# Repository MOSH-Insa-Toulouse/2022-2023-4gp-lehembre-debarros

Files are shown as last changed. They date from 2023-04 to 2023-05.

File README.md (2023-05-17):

# 2022-2023-4gp-lehembre-debarros

## SOMMAIRE 

1. Etapes de fabrication
2. Présentation du capteur graphite 
3. Simulations sous LtSpice
4. Circuit électronique
5. Eléments nécessaires au projet
6. Elaboration du shield sous KiCAD
7. Programme Arduino
8. Application Android
9. Banc de test
10. Datasheet 

# 1. Etapes de fabrication

- Création du circuit et simulations sous LtSpice
- Implémentation du circuit sous KiCAD et élaboration du PCB 
- Fabrication du PCB
- Percage de la plaquette et soudure des composants 
- Elaboration du code Arduino
- Création de l'application d'interfacage sous MIT - app inventor
- Caractérisation du capteur

# 2. Présentation du capteur graphite 

Le capteur est basé sur l'effet tunnel quantique entre les particules de graphite déposées par le crayon. 
Pour plus d'informations, vous pouvez vous renseigner grâce au lien suivant : [Informations supplémentaires](https://github.com/MOSH-Insa-Toulouse/2022-2023-4gp-lehembre-debarros/blob/d776b440ef20fb4f5e64abb67d3f56df1f3a449e/++Publi%20Pencil%20Drawn%20Strain%20Gauges-srep03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)

Dimensions : 



Utilisation d'un crayon HB pour le grain.

# 3. Simulations sous LtSpice

Etude et dimensionnement du gain et des capacités afin d’obtenir un signal exploitable en simulant le circuit : 



La résistance du capteur est calculé grâce à la formule suivante : 𝑅_𝐶=((𝑅_3+𝑅_2) 𝑅_1 𝑉_𝐶𝐶)/(𝑅_2 𝑉_𝐴𝐷𝐶)−𝑅_5−𝑅_1

# 4. Circuit électronique 

Schéma de l'amplificateur de signal :
 


Modules supplémentaires et leur connexions : 



Connection des pins entre le PCB et la carte Arduino



# 5. Eléments nécessaires au projet 

-	Arduino Uno
-	Module Bluetooth HC05
-	Amplificateur LTC1050 
-	I2C Ecran OLED Joy-it SBC-OLED01
-	Encodeur rotatoire avec boutton poussoir (Joy-it KY-040) 
-	Spectrasymbol 005 21 Flex Sensor
-	MCP41050 SPI Potentiomètre Digital 

# 6. Elaboration du PCB sous KiCAD

Représentation du PCB avec le circuit implémenté : 



Empruntes des autres composants : 



# 7. Programme Arduino

Ci-après, le code Arduino utilisé : [Code Arduino](https://github.com/MOSH-Insa-Toulouse/2022-2023-4gp-lehembre-debarros/blob/07b504035136efd2108f1f7b01446d1b1bee7c57/Code_arduino_Lauriane_Alan.ino)

# 8. Application Android

L'APK est disponible à cette adresse : [APK](https://github.com/MOSH-Insa-Toulouse/2022-2023-4gp-lehembre-debarros/blob/c0ea48ad6c8dff68e6e4c520c7baa0256ce2a0f2/Capteur_Graphite_Final.apk)



# 9. Banc de test

Pour calibrer notre capteur, nous avons utilisé le banc de test mis à notre disposition. 



Nous avons ainsi obtenu les variations relatives suivantes en tension et en compression : 
 

Notre capteur dispose ainsi d'une sensibilité de 0,675 GΩ/% en compression et 0,2GΩ/% en tension.

Cette sensibilité correspond au coefficient de la pente de la variation relative par rapport à la déformation. 
La déformation se calcule à l'aide de la formule suivante : ɛ = e/(2.R).

- ɛ : déformation
- e : épaisseur du papier utilisé (0,16mm ici)
- R : rayon de la courbe

These values are for comparative use only to get orders of magnitude, they are very unstable until the sensor is stabilized in a specialized housing. 

# 10. Datasheet

La datasheet est disponible en suivante le lien ci-après : [Datasheet](https://github.com/MOSH-Insa-Toulouse/2022-2023-4gp-lehembre-debarros/blob/0e1e4ce1e155748c3f02e4ec9dddf21011c97965/Datasheet%20-%20Capteur-final.pdf)

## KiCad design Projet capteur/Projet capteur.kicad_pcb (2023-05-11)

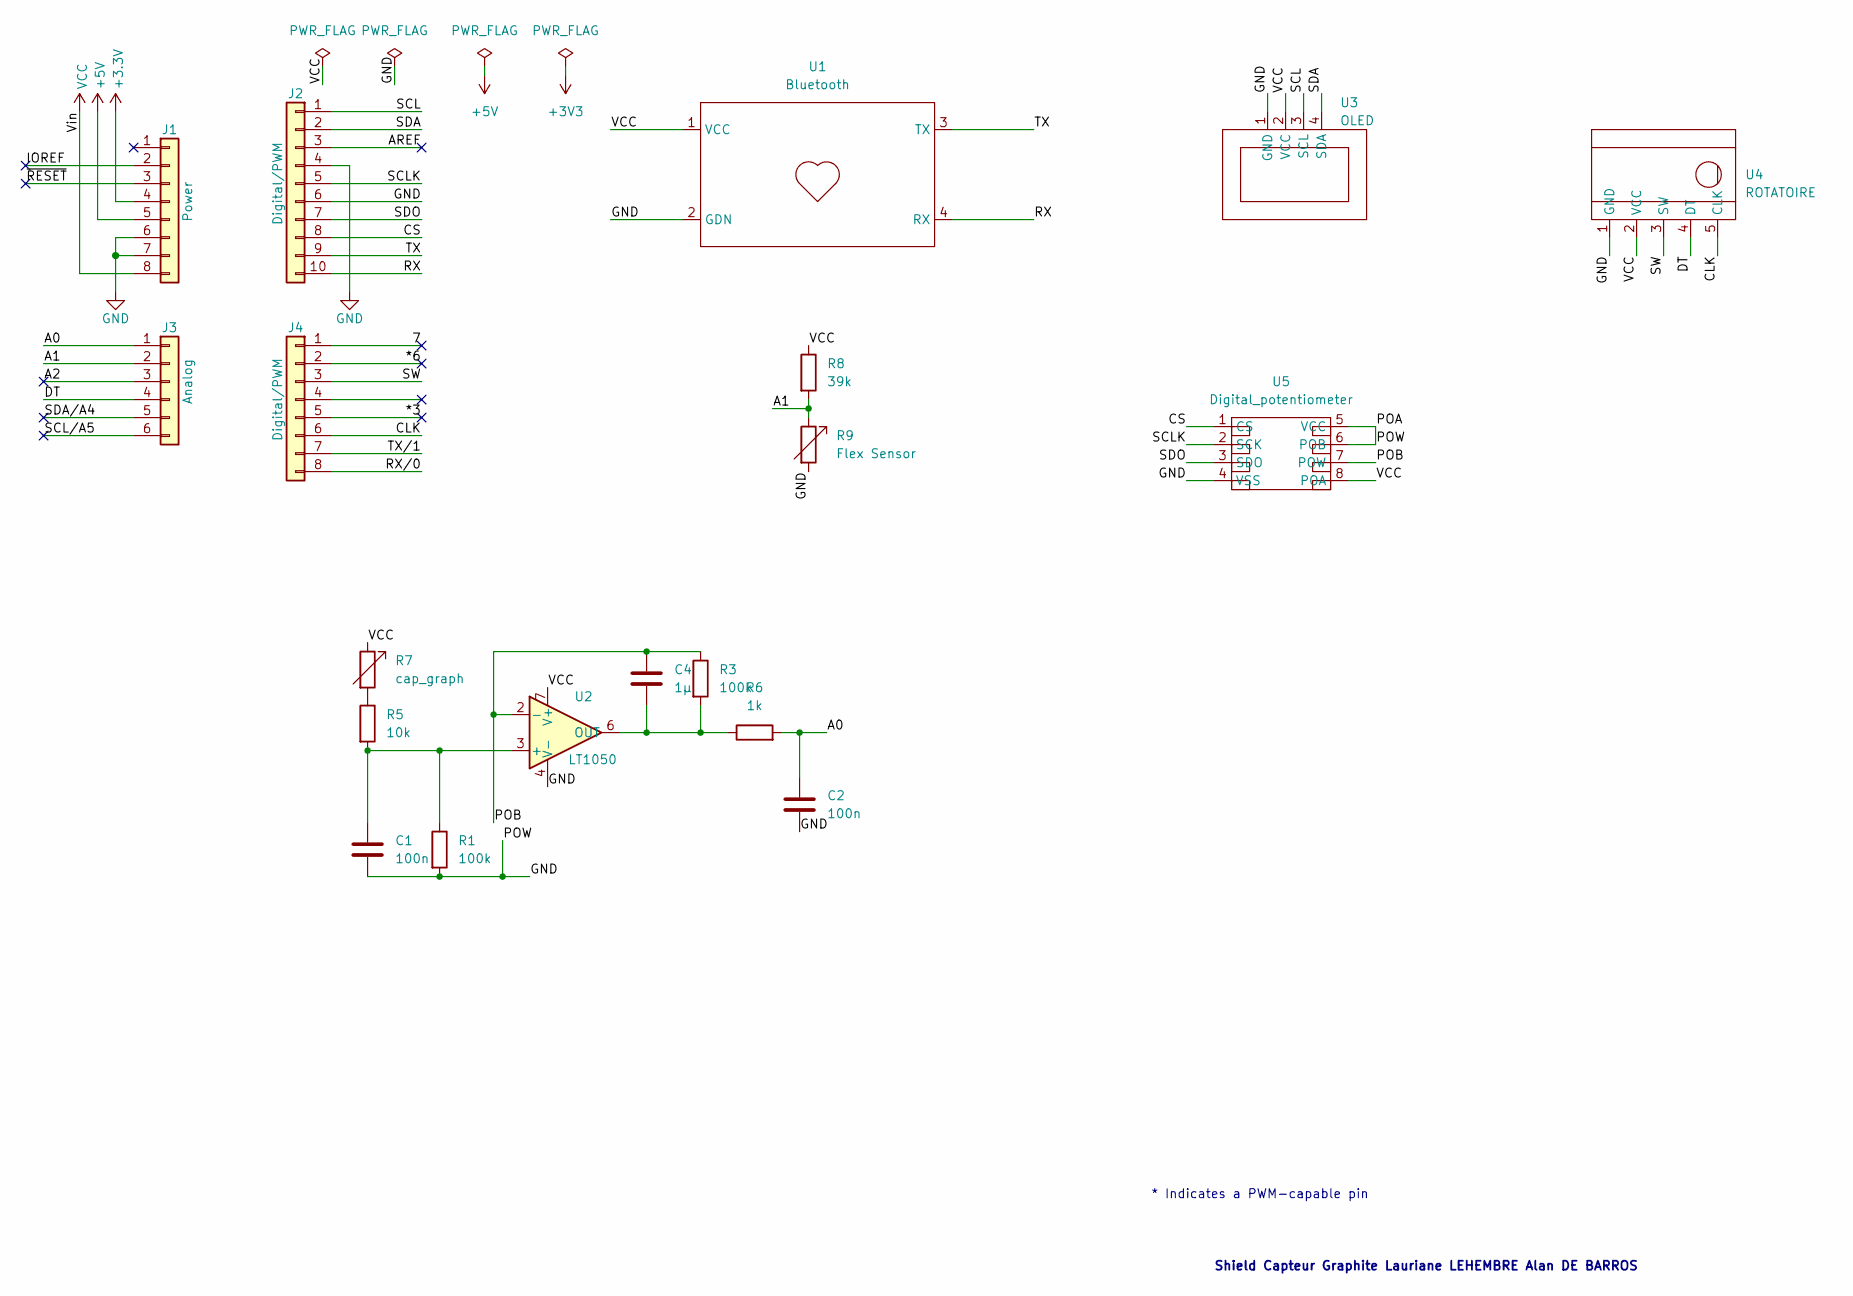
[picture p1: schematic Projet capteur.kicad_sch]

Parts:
C1, C2: 100n; capa
C4: 1µ; C4
J1: Power; PinSocket_1x08_P2.54mm_Vertical
J2: Digital/PWM; PinSocket_1x10_P2.54mm_Vertical
J3: Analog; PinSocket_1x06_P2.54mm_Vertical
J4: Digital/PWM; PinSocket_1x08_P2.54mm_Vertical
R1, R3: 100k; Resistance
R5: 10k; Resistance
R6: 1k; Resistance
R7: cap_graph; Flex_sensor
R8: 39k; Resistance
R9: Flex Sensor; Flex_sensor
U1: Bluetooth; Bluetooth_4pattes
U2: LT1050; DIP-8_W7.62mm_LongPads
U3: OLED
U4: ROTATOIRE; Rotatoire
U5: Digital_potentiometer; Pot_Digital

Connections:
+3V3: J1.4
+5V: J1.5
/7: J4.1
/*3: J4.5
/*6: J4.2
/A0: C2.1, J3.1, R6.2
/A1: J3.2, R8.2, R9.1
/A2: J3.3
/AREF: J2.3
/CLK: J4.6, U4.5 (CLK)
/CS: J2.8, U5.1 (CS)
/DT: J3.4, U4.4 (DT)
/IOREF: J1.2
/POB: C4.1, R3.1, U2.2 (-), U5.7 (POW)
/RX: J2.10, U1.4 (RX)
/RX/0: J4.8
/SCL: J2.1, U3.3 (SCL)
/SCLK: J2.5, U5.2 (SCK)
/SCL/A5: J3.6
/SDA: J2.2, U3.4 (SDA)
/SDA/A4: J3.5
/SDO: J2.7, U5.3 (SDO)
/SW: J4.3, U4.3 (SW)
/TX: J2.9, U1.3 (TX)
/TX/1: J4.7
/~RESET: J1.3
GND: C1.2, C2.2, J1.6, J1.7, J2.4, J2.6, R1.2, R9.2, U1.2 (GDN), U2.4 (V-), U3.1 (GND), U4.1 (GND), U5.4 (VSS), U5.5 (VCC), U5.6 (POB)
unnamed: R5.1, R7.2
unnamed: C1.1, R1.1, R5.2, U2.3 (+)
unnamed: C4.2, R3.2, R6.1, U2.6 (OUT)
VCC: J1.8, R7.1, R8.1, U1.1 (VCC), U2.7 (V+), U3.2 (VCC), U4.2 (VCC), U5.8 (POA)

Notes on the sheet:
Shield Capteur Graphite Lauriane LEHEMBRE Alan DE BARROS
* Indicates a PWM-capable pin

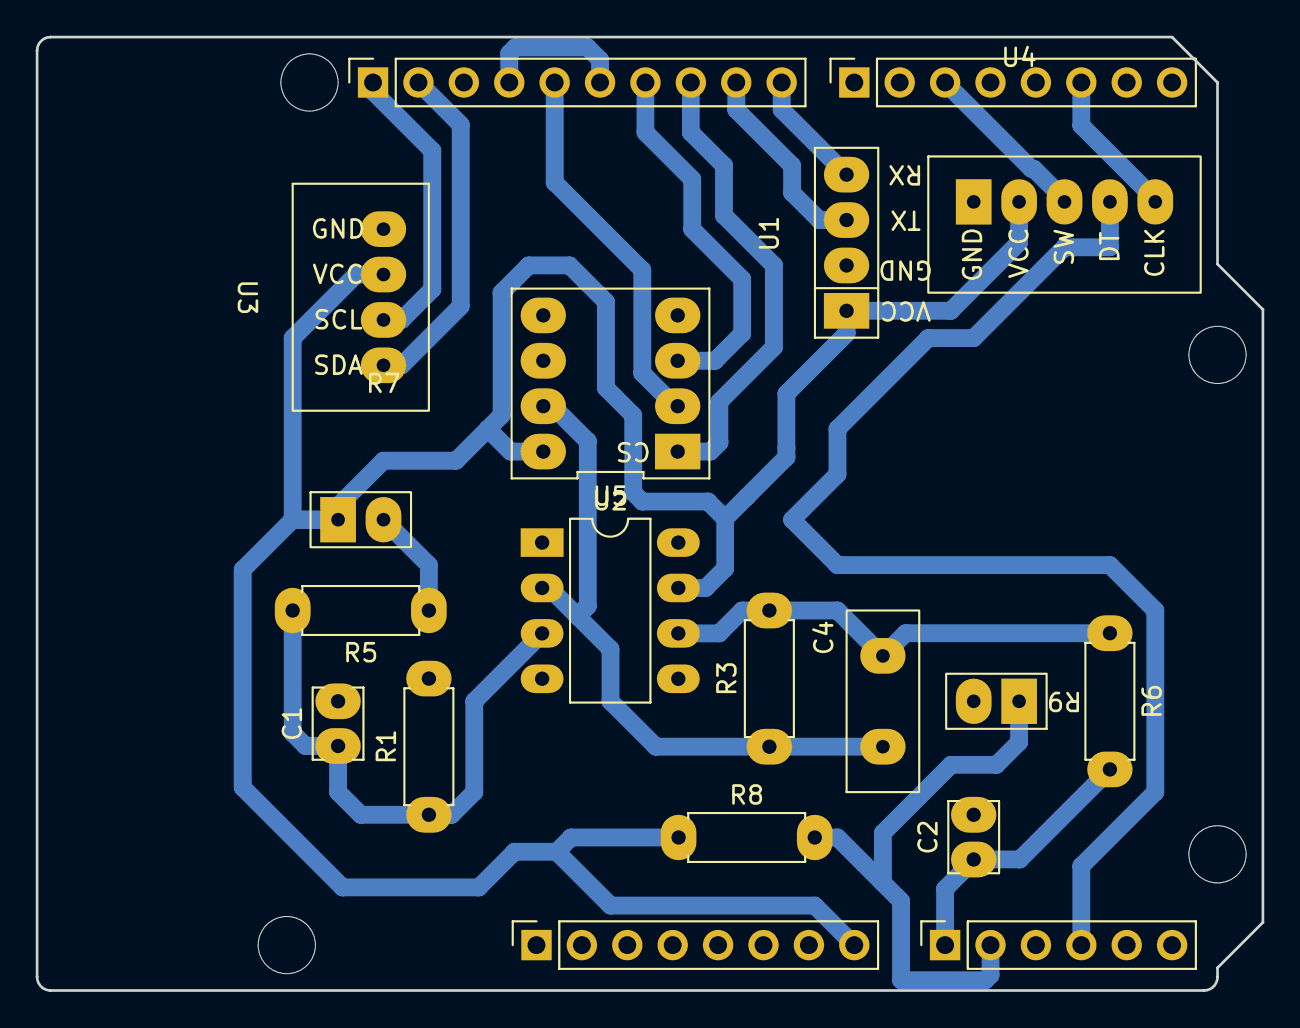
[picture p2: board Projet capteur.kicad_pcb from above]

Board: 2 copper layers, 68.6 x 53.3 mm, 23 parts (0 on the bottom side), 18 nets.

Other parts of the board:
MH1, MH2, MH3, MH4: MountingHole_3.2mm

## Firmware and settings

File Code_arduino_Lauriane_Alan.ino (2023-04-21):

#include <SoftwareSerial.h>
#include <SPI.h>
#include <Adafruit_SSD1306.h>

////////////////////////////////////////////////////////////////////////////////////////////////////////
#define nombreDePixelsEnLargeur 128         // Taille de l'écran OLED, en pixel, au niveau de sa largeur
#define nombreDePixelsEnHauteur 64          // Taille de l'écran OLED, en pixel, au niveau de sa hauteur
#define brocheResetOLED         -1          // Reset de l'OLED partagé avec l'Arduino (d'où la valeur à -1, et non un numéro de pin)
#define adresseI2CecranOLED     0x3C  
#define encoder0PinA  2  //CLK Output A Do not use other pin for clock as we are using interrupt
#define encoder0PinB  4  //DT Output B
#define Switch 5 // Switch connection if available
#define MCP_NOP 0b00000000
#define MCP_WRITE 0b00010001
#define MCP_SHTDWN 0b00100001
#define txPin 8   //Broche 11 en tant que RX, TX du HC-05
#define rxPin 9   //Broche 10 en tant que TX, RX du HC-05
#define baudrate 9600
////////////////////////////////////////////////////////////////////////////////////////////////////////

const int ssMCPin = 10; // Define the slave select for the digital pot
volatile unsigned int encoder0Pos = 0; //Valeur de position de l'encodeur rotatoire
int in_menu = 0; //Booleen permettant de switch entre menu et fonctionnalités
int last_pos_encodeur = 0; //Dernière position de l'encodeur rotatoire, pour savoir si la position a changé depuis le dernier tour de boucle
int pos_menu = 1; //Position dans le menu 
float R2 = 5*196.08; //Valeur de R2, initialisée à environ 980 
float sensorfelix = 0.0; //Valeur de tension du flexsensor 
int buttonState;   // lecture actuelle du pin d'entrée du bouton poussoir
int lastButtonState = 0; //Dernière valeur de l'entrée du bouton poussoir
long lastDebounceTime = 0; // the last time the output pin was toggled
long debounceDelay = 10;    // temps de debouncing 


Adafruit_SSD1306 ecranOLED(nombreDePixelsEnLargeur, nombreDePixelsEnHauteur, &Wire, brocheResetOLED); //definition de l'OLED 
SoftwareSerial mySerial(rxPin ,txPin); //Definition du software serial pour le bluetooth 

//SPIWrite est une fonction qui sera appelee pour ecrire des valeurs sur le potentiometre digital 
void SPIWrite(uint8_t cmd, uint8_t data, uint8_t ssPin) // SPI write the command and data to the MCP IC connected to the ssPin
{
  SPI.beginTransaction(SPISettings(14000000, MSBFIRST, SPI_MODE0)); //https://www.arduino.cc/en/Reference/SPISettings
  digitalWrite(ssPin, LOW); // SS pin low to select chip
  SPI.transfer(cmd);        // Send command code
  SPI.transfer(data);       // Send associated value
  digitalWrite(ssPin, HIGH);// SS pin high to de-select chip
  SPI.endTransaction();
}

//---------------------------------------------------------------------------------------


void setup() {

//Setup des pins de l'encodeur rotatoire et de l'interrupt ------------------------------
  pinMode(encoder0PinA, INPUT);  
  digitalWrite(encoder0PinA, HIGH);       // turn on pullup resistor
  pinMode(encoder0PinB, INPUT); 
  digitalWrite(encoder0PinB, HIGH);       // turn on pullup resistor
  attachInterrupt(0, doEncoder, RISING); // encoder pin on interrupt 0 - pin2
//---------------------------------------------------------------------------------------

//Setup de l'ecran OLED ------------------------------------------------------------------------------------
      if(!ecranOLED.begin(SSD1306_SWITCHCAPVCC, adresseI2CecranOLED))
    while(1);                               // Arrêt du programme (boucle infinie) si échec d'initialisation
    boolean bCouleurInverse = false;
    ecranOLED.clearDisplay();  // Effaçage de l'intégralité du buffer de l'ecran 
    ecranOLED.setTextSize(1);  // Taille de la police d'ecriture
    ecranOLED.setCursor(0,30 ); //Position initiale du curseur 
    ecranOLED.setTextColor(SSD1306_WHITE, SSD1306_BLACK); //Couleur d'ecriture initiale             
//----------------------------------------------------------------------------------------------------------
  

//Setup des pins serie et debut de communication sur les differents ports 
  // initialize serial communication at 9600 bits per second:
  Serial.begin(baudrate);
  pinMode(rxPin,INPUT);
  pinMode(txPin,OUTPUT);
  pinMode (ssMCPin, OUTPUT); //select pin output
  digitalWrite(ssMCPin, HIGH); //SPI chip disabled
  SPI.begin();  
  mySerial.begin(baudrate);
//------------------------------------------------------------------------

}


void loop() {

  int i_R2 = 5; //Initialisation de la position du wiper dans le pot. digital

  //Code des 3 fonctionnalités qui s'executent en dehors du menu principal selon la valeur de pos_menu 
  if (not in_menu){ //Si on n'est pas dans le menu alors... 
     
      if(pos_menu == 1){ //Si pos_menu vaut 1 on rentre dans la fonctionnalité reglage du gain, en choisissant R2, la resistance serie sur la borne V- de l'ampli-op
        i_R2 = 0; //On passe le wiper a 0 
        buttonState = 0; //On force l'etat actuel du bouton poussoir a 0, car il n'est pas re-lu et vaut toujours 1 en sortant du menu 
        delay(100); //Delai pour la stabilite 

        while(!buttonState){ //Tant que le bouton poussoir n'a pas ete presse 
            //Serial.println("on passe ici"); //Pour debugguer :) 
            if (last_pos_encodeur != encoder0Pos) { //Si la position de l'encodeur rotatoire a change <=> il a tourne alors... 
                          if(i_R2 < 255){ //Si la position du wiper vaut 254 ou moins, on l'incremente de 1 
                            i_R2++;
                          }
                          else{ //Si elle vaut deja 255, alors elle repasse a 0 
                            i_R2 = 0; 
                          }
                          last_pos_encodeur = encoder0Pos; //Changement de la derniere position de l'encodeur, pour le prochain tour de boucle 
                          
              }
            //Affiche sur l'ecran oled de la valeur de R2 a chaque tour de boucle 
            ecranOLED.clearDisplay(); //Clear de l'ecran 
            ecranOLED.setCursor(0, 30); 
            ecranOLED.print("R2 vaut ");
            ecranOLED.print(i_R2*196.08);
            ecranOLED.display();
            ecranOLED.setCursor(0, 30); 
            //-------------------------------------------------------------------
            
            buttonState = Bouton(&lastButtonState, &lastDebounceTime); //Lecture du bouton poussoir, a l'aide d'une fonction dediee 

        }
        //Une fois qu'on sort de la boucle de reglage de R2 
        R2 = (float)i_R2*196.08;
        delay(300); //Delai pour stabilite 
        SPIWrite(MCP_WRITE, i_R2, ssMCPin); //ecriture de R2 dans le pot. digital 
        in_menu = 1; //On retourne dans le menu
       }
       
      else if(pos_menu == 2){ //Si pos_menu == 2, alors on passe dans la fonctionnalite lecture de Rgraphite et envoi par Bluetooth sur l'appli

        int sensorValue = analogRead(A0); //Lecture tension de sortie de l'ampli-op 
        //Serial.println(sensorValue); //Pour observer sur ordinateur la tension, si necessaire 
        float tension_graphite = (float)sensorValue * 5.0/1023.0; //Conversion valeur ADC vers tension en volts 
        float Rc = ((100000.0*(100000.0+R2)*4.2968)/(R2*tension_graphite)) - 10000.0 - 100000.0; //Calcul de Rgraphite avec la fonction de transfert du circuit

        //Affichage de Rgraphite sur l'ecran oled         
        ecranOLED.clearDisplay();
        ecranOLED.setCursor(0, 30);
        ecranOLED.print("Rgraph vaut :");
        ecranOLED.println(Rc);
        ecranOLED.display();
        ecranOLED.setCursor(0, 30);
        //---------------------------------------

        //Envoi de la valeur en sortie d'ADC vers l'application via le module bluetooth HC-05 
        uint8_t sensorBT = sensorValue/4; //Variable permettant de cantonner la valeur sur un byte car synchronisation du transfert de donnee sur plusieurs octets 
        //tres difficile avec l'application android et le module bluetooth, engendre des bugs. On perd un facteur 4 de resolution sur l'appli (20mV au lieu de 5)
        mySerial.write(sensorBT); //Envoi par bluetooth en serial 
        delay(100); //Delai car le transfert de donnee prend du temps + stabilite 
        
         //Si l'encodeur rotatoire a tourne depuis le dernier tour de boucle, on revient dans le menu 
        if (last_pos_encodeur != encoder0Pos) {
              in_menu = 1; 
              last_pos_encodeur = encoder0Pos; 
            }
        //--------------------------------------------------------------------------------------------
      }

      else if (pos_menu ==  3){ //Fonctionnalite lecture de la resistance du flex sensor 
      //Serial.println("Nous sommes dans le case 3"); //Pour debug 

        int felixsensor = analogRead(A1);
        float sensorfelix = (39000.0*4.2968)/(4.2968 - (float)felixsensor*(5.0/1023.0));

        //Affichage OLED ---------------
        ecranOLED.clearDisplay();
        ecranOLED.setCursor(0, 30);
        ecranOLED.print("Rflex vaut :");
        ecranOLED.println(sensorfelix);
        ecranOLED.display();
        ecranOLED.setCursor(0, 30);
        //-------------------------------

        delay(100);
        
        //Retour menu si l'encodeur rotatoire tourne 
        if (last_pos_encodeur != encoder0Pos) {
              in_menu = 1; 
              last_pos_encodeur = encoder0Pos; 
            }
        //------------------------------------------
      }
      else{
        Serial.println("Il y a eu un bug, déso"); //Exception si pos_menu se prend un rayon cosmique et prend une valeur impossible :) 
      }

  }
  else { //Programme du menu 
  
    //Serial.println("Nous sommes dans le menu");  //Pour debug 

    //Affichage du menu, la ligne correspondant a la fonction selectionnee par pos_menu est en surbrillance 
    ecranOLED.clearDisplay();
    ecranOLED.setCursor(0, 10);
    
    if (pos_menu == 1){ecranOLED.setTextColor(SSD1306_BLACK, SSD1306_WHITE);} 
    ecranOLED.print("Parametrer R2\n");
    if (pos_menu == 1){ecranOLED.setTextColor(SSD1306_WHITE, SSD1306_BLACK);}

    if (pos_menu == 2){ecranOLED.setTextColor(SSD1306_BLACK, SSD1306_WHITE);}
    ecranOLED.print("Observer Rgraph\n");
    if (pos_menu == 2){ecranOLED.setTextColor(SSD1306_WHITE, SSD1306_BLACK);}
    
    if (pos_menu == 3){ecranOLED.setTextColor(SSD1306_BLACK, SSD1306_WHITE);}
    ecranOLED.print("Observer Rflex");
    if (pos_menu == 3){ecranOLED.setTextColor(SSD1306_WHITE, SSD1306_BLACK);}

    ecranOLED.display();

    //-----------------------------------------------------------------------------------------------------

    // Serial.println("Le bouton est a:"); //Pour debug 
    // Serial.println(buttonState);
  
    //Code de selection de la fonctionnalite 
     if (last_pos_encodeur != encoder0Pos) { //Si l'encodeur rotatoire tourne, pos_menu est incremente entre 1 et 3, puis repasse a 1 
               last_pos_encodeur = encoder0Pos; 
               if(pos_menu<3){
                 pos_menu++;
                 }
               else{
                 pos_menu=1;
                 }
              
       }

    buttonState = Bouton(&lastButtonState, &lastDebounceTime); //Lecture du bouton poussoir 
    if(buttonState){ //Si le bouton est appuye alors on sort du menu, pos_menu ne change pas donc on entre dans la bonne fonctionnalite 
      in_menu = 0;
    }
    delay(50); //Pour la stabilite 
  }
  

}


//Fonction qui gere l'interrupt de l'encodeur rotatoire et incremente ou decremente sa position selon l'etat du pin encoder0PinB 
void doEncoder() {
  if (digitalRead(encoder0PinB)==HIGH) {
    encoder0Pos++;
  } else {
    encoder0Pos--;
  }
}
//-------------------------------------------------------------------------------------------------------------------------------

//Fonction de lecture du bouton poussoir, avec debouncing pour eviter les flickerings et mauvaises lectures 
int Bouton(int * LBS, long * LBT) { //On passe par des pointeurs pour pouvoir modifier des variables passees en entree de la fonction 
    int Bout_state = 0; 
    int reading = analogRead(A3); //On utilise une entree analogique car la tension du bouton ne suffit pas a declencher un haut niveau logique en entree digitale
      if(reading > 10){ //Lorsque le bouton n'est pas appuye on a un niveau de tension d'environ 1V 
        reading = 0; 
      }
      else{
        reading = 1; 
      }
 

      // check to see if you just pressed the button
      // (i.e. the input went from LOW to HIGH),  and youve waited
      // long enough since the last press to ignore any noise:  
      // If the switch changed, due to noise or pressing:
      if (reading != *LBS) { //Si la valeur de lecture a change (bruit ou intentionnel)
       
        *LBT = millis();  // reset du timer de deboucing 

      }
    
      if ((millis() - *LBT) > debounceDelay)
      {
        // whatever the reading is at, it's been there for longer
        // than the debounce delay, so take it as the actual current state:
        Bout_state = reading;
      }

    *LBS = reading; 
    //  Serial.print("state = ");
    //  Serial.println(reading);
     
    //Serial.println(Bout_state); //Pour debug
    return Bout_state;   

}

//---------------------------------------------------------------------------------
                                        //FIN DU CODE, Merci pour votre attention// 

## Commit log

2023-04-21 Ajout du code arduino
2023-04-21 APK de l'application Android
2023-05-11 Update Projet capteur.kicad_pro
